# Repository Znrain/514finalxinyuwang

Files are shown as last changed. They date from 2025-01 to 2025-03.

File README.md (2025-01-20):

# 📌 514 Final Project

## 1️⃣ Project Overview
This project is designed to **measure pressure and temperature** using an **MS5837-30BA sensor** and display the results using a **stepper-motor-driven gauge needle**. The system is powered by an **ESP32-S3 microcontroller**, which processes the data and transmits it wirelessly if needed.

### **Physical Features:**
- **Sensor Device**: MS5837-30BA pressure and temperature sensor.
- **Processing Unit**: ESP32-S3 for data collection and control.
- **Display Device**: A stepper-motor-driven gauge needle for analog-style visualization.
- **Power Source**: LiPo battery for wireless operation.

**System Architecture Sketch:**  
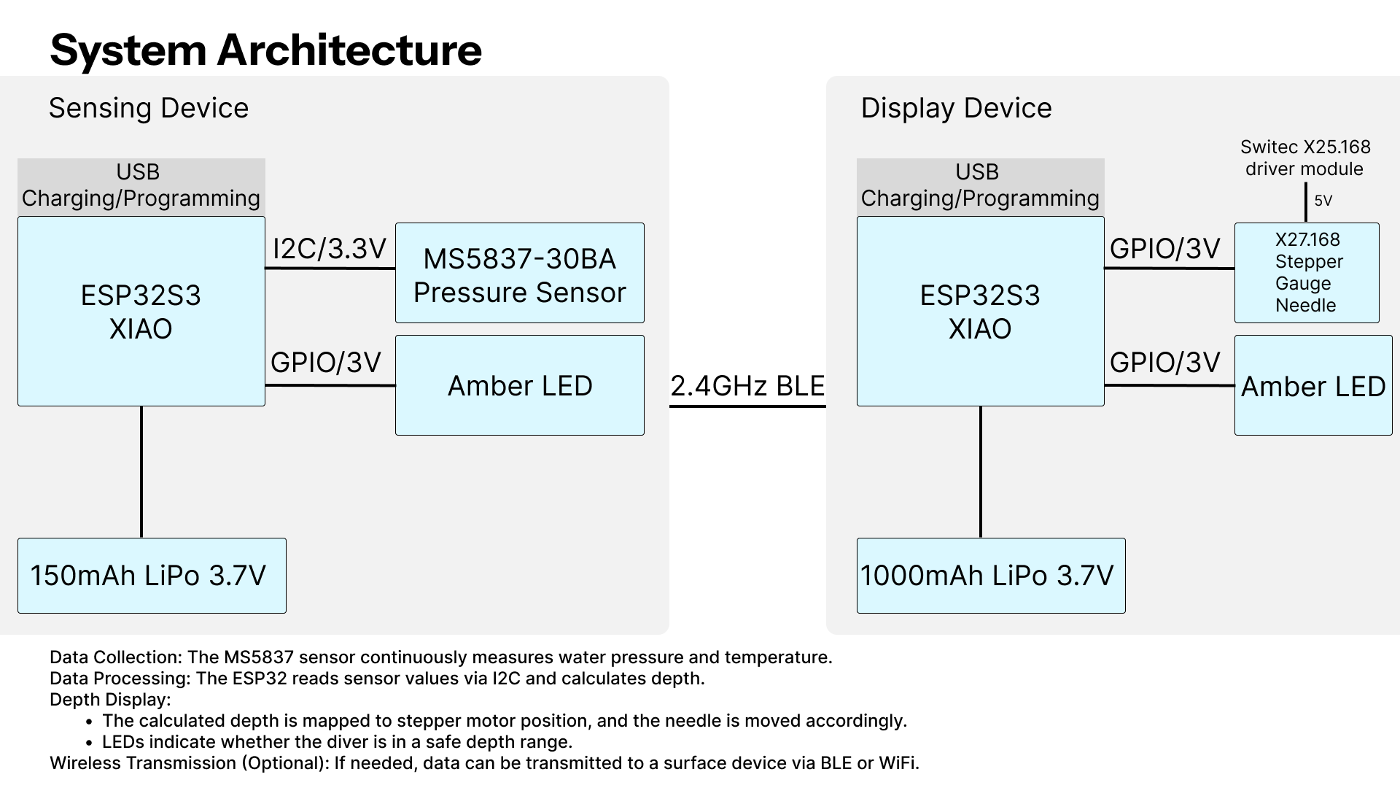
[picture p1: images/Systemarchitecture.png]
System Architecture


---

## 2️⃣ Sensor Device: MS5837-30BA
The **MS5837-30BA** is a **pressure and temperature sensor** that communicates with the ESP32-S3 via the **I2C protocol**. It is used to measure environmental **pressure** and **temperature** in real-time.

### **How it Works:**
- The **sensor measures pressure** in millibars (mbar) and **temperature** in degrees Celsius (°C).
- It transmits data to the **ESP32-S3 via I2C**.
- The ESP32 processes the data and prepares it for display.

### **Sensor Diagram:**
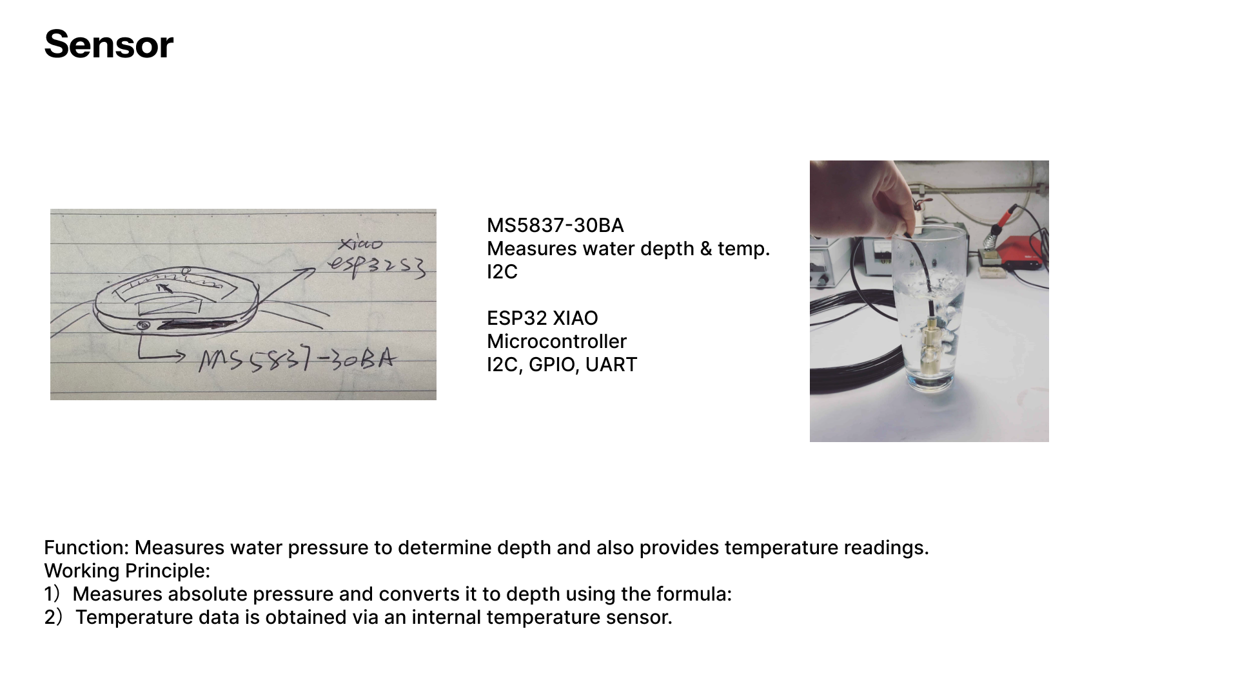
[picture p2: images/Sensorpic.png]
Sensor Device


### **Sensor Part Number:**
- **Pressure & Temperature Sensor**: MS5837-30BA  

---

## 3️⃣ Display Device: Stepper-Motor-Driven Gauge Needle
The **stepper motor with a gauge needle** provides an **analog-style display** of pressure readings. The needle moves proportionally to the measured pressure.

### **How it Works:**
- The **ESP32-S3** sends control signals to the **motor driver**.
- The **stepper motor rotates** to move the gauge needle.
- The **needle position** corresponds to the measured pressure.
- The **display updates in real-time**.

### **Display Diagram:**
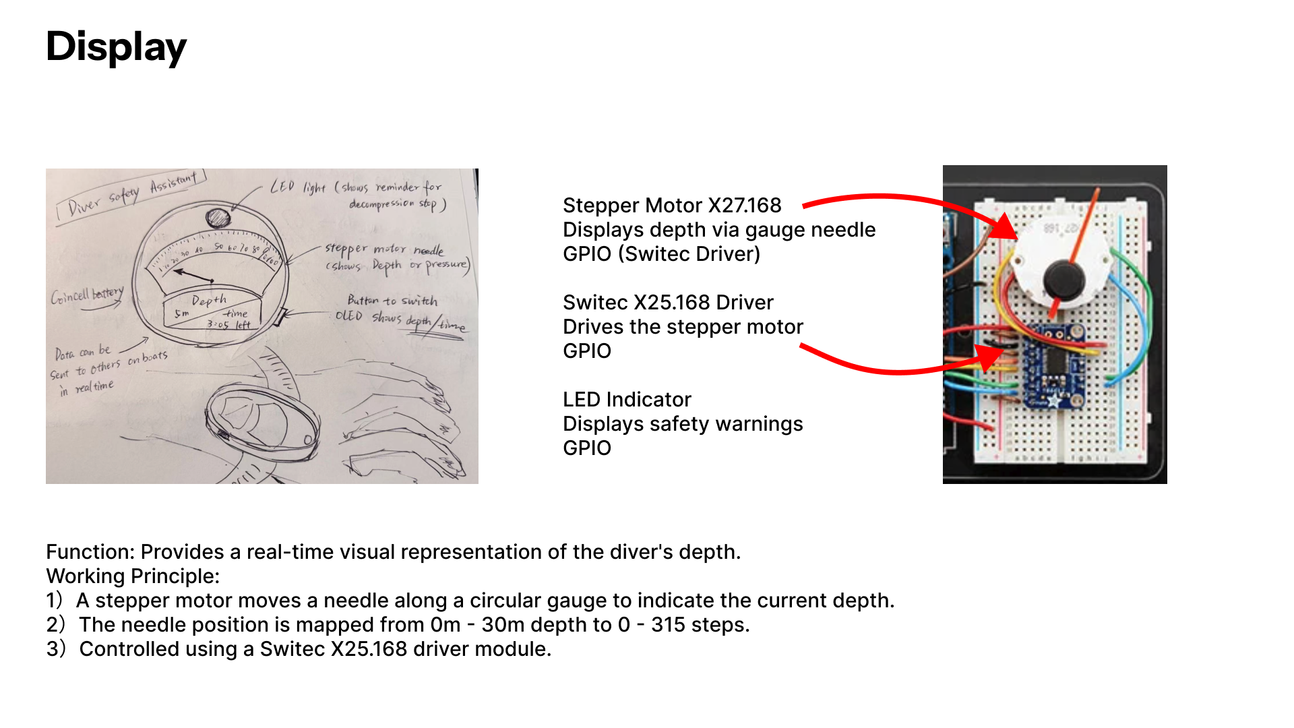
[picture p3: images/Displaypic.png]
Display Device


### **Display Components & Part Numbers:**
- **Stepper Motor**: X25-589  
- **Motor Driver**: SP_X27_e_C  

---

## 4️⃣ System Communication & Detailed Diagram
The **ESP32-S3** acts as the central unit, reading sensor data, processing it, and sending commands to the display.

### **Communication Flow:**
1. **MS5837-30BA sensor** measures pressure and temperature.
2. The sensor **sends data via I2C** to the ESP32-S3.
3. The **ESP32 processes the data** and converts it into a stepper motor signal.
4. The **motor driver (SP_X27_e_C) moves the gauge needle** to display pressure.
5. Optional: **Wireless transmission** can be added using **ESP32's 2.4GHz antenna**.

### **System Diagram:**
**Device Communication Chart**:  
System Architecture

---

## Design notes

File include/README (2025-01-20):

# Diver Safety Assistant

## 🌊 Overview
This is a **diving assistant device** that helps divers track **depth and temperature** in real-time. The system consists of:
- **A sensor device** attached to the diver that collects water depth and temperature data.
- **A display device** that shows real-time depth and alerts the diver using an LED.

## 🎨 Sketch
Project Sketch

---
## 🔗 System Architecture

### **How Devices Communicate**
System Communication Diagram

### **Function Details**
Function Flowchart

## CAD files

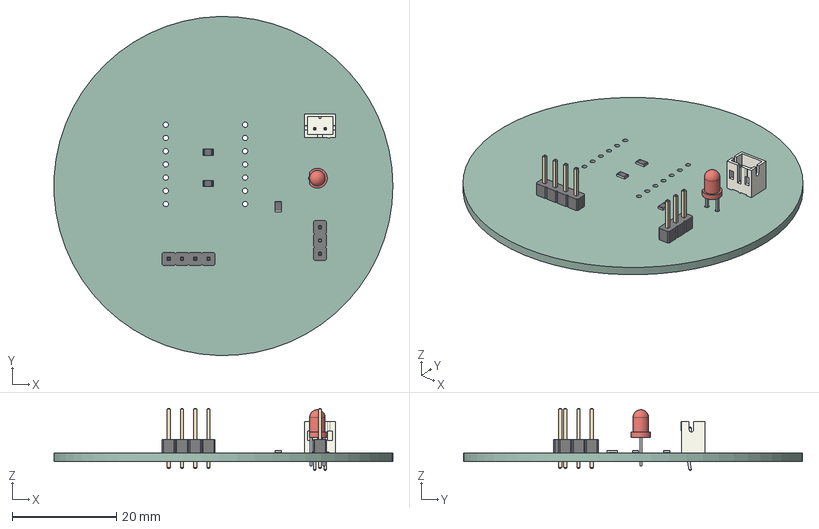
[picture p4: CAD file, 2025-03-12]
PCBSTEPexport/514finalsensor.step
65.1 x 65.1 x 11.9 mm
LED_D3.0mm
PinHeader_1x04_P254mm_Vertical
JST_B2B_PH_K
PinHeader_1x03_P254mm_Vertical
R_0805_2012Metric x 3
514finalsensor_PCB

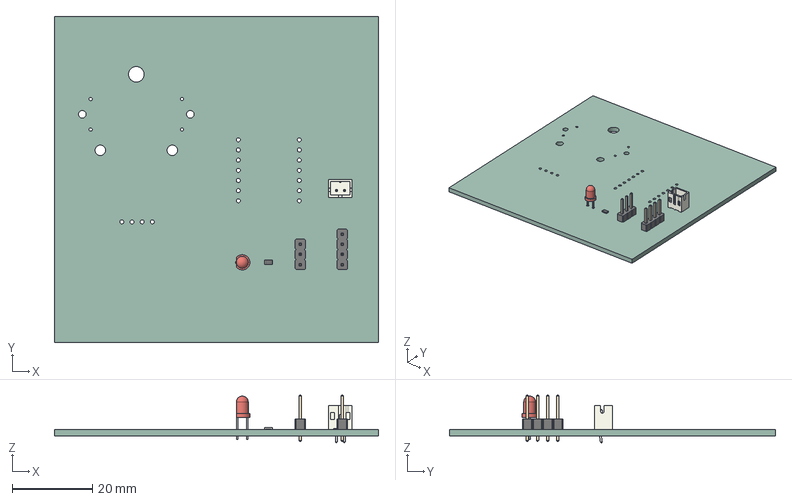
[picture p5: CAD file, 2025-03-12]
PCBSTEPexport/514finalpcbdesign.step
81.0 x 81.5 x 11.9 mm
PinHeader_1x04_P254mm_Vertical
R_0805_2012Metric
PinHeader_1x03_P254mm_Vertical
LED_D3.0mm
JST_B2B_PH_K
514finalpcbdesign_PCB

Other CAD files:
PCBSTEPexport/514finalshell v5.f3d

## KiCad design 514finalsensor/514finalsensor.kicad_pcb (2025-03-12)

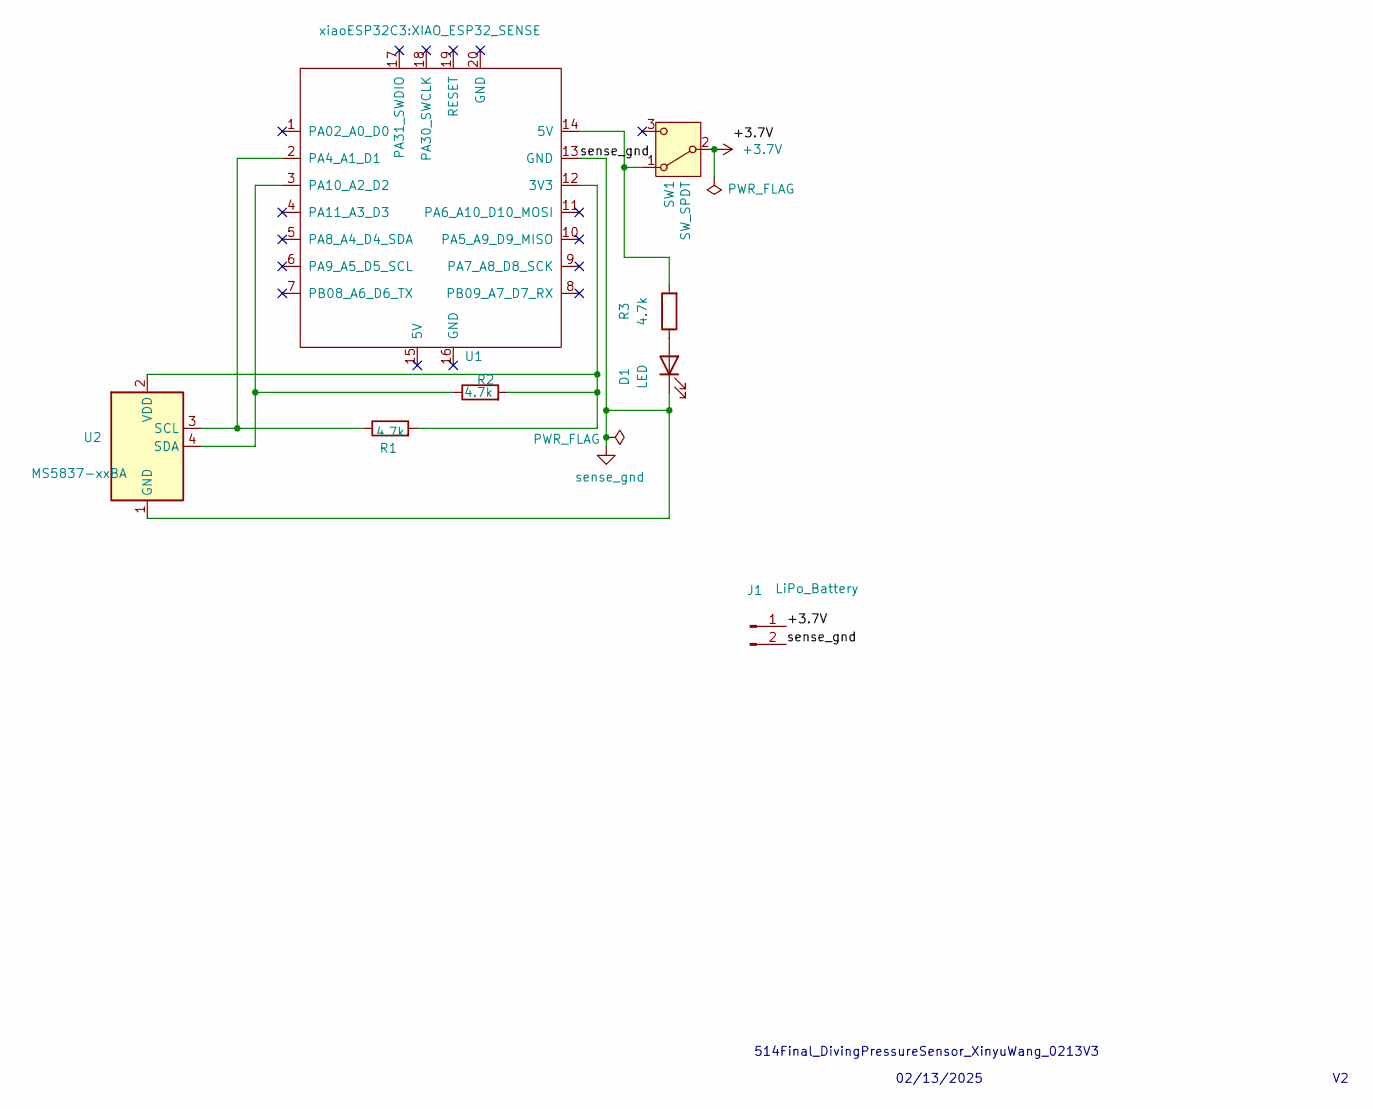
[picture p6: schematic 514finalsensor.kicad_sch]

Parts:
D1: LED; LED_D3.0mm
J1: LiPo_Battery; JST_PH_B2B-PH-K_1x02_P2.00mm_Vertical
R1, R2, R3: 4.7k; R_0805_2012Metric_Pad1.20x1.40mm_HandSolder
SW1: SW_SPDT; PinHeader_1x03_P2.54mm_Vertical
U1: SeeeduinoXIAO; XIAO_ESP32_SENSE
U2: MS5837-xxBA; PinHeader_1x04_P2.54mm_Vertical

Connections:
+3.7V: J1.1, SW1.2 (B)
unnamed: D1.2 (A), R3.1
unnamed: R3.2, SW1.1 (A), U1.14 (5V)
unnamed: R1.2, R2.2, U1.12 (3V3), U2.2 (VDD)
unnamed: R1.1, U1.2 (PA4_A1_D1), U2.3 (SCL)
unnamed: R2.1, U1.3 (PA10_A2_D2), U2.4 (SDA)
sense_gnd: D1.1 (K), J1.2, U1.13 (GND), U2.1 (GND)

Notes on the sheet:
514Final_DivingPressureSensor_XinyuWang_0213V3
02/13/2025

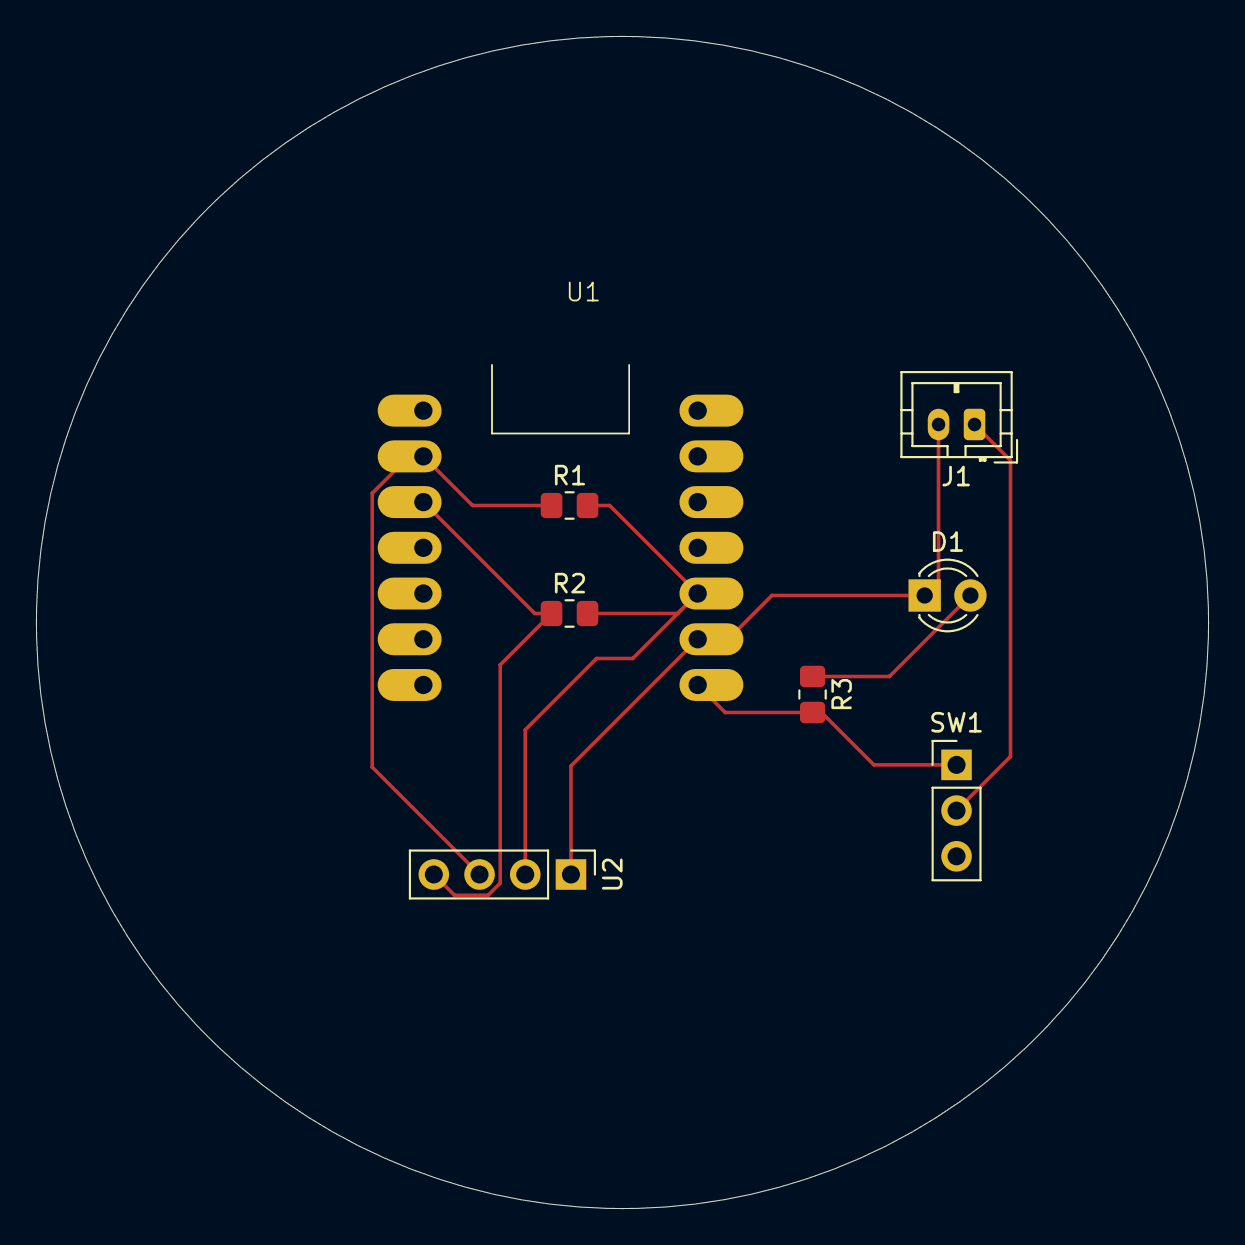
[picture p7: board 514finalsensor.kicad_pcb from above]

Board: 2 copper layers, 65.1 x 65.1 mm, 8 parts (0 on the bottom side), 7 nets.

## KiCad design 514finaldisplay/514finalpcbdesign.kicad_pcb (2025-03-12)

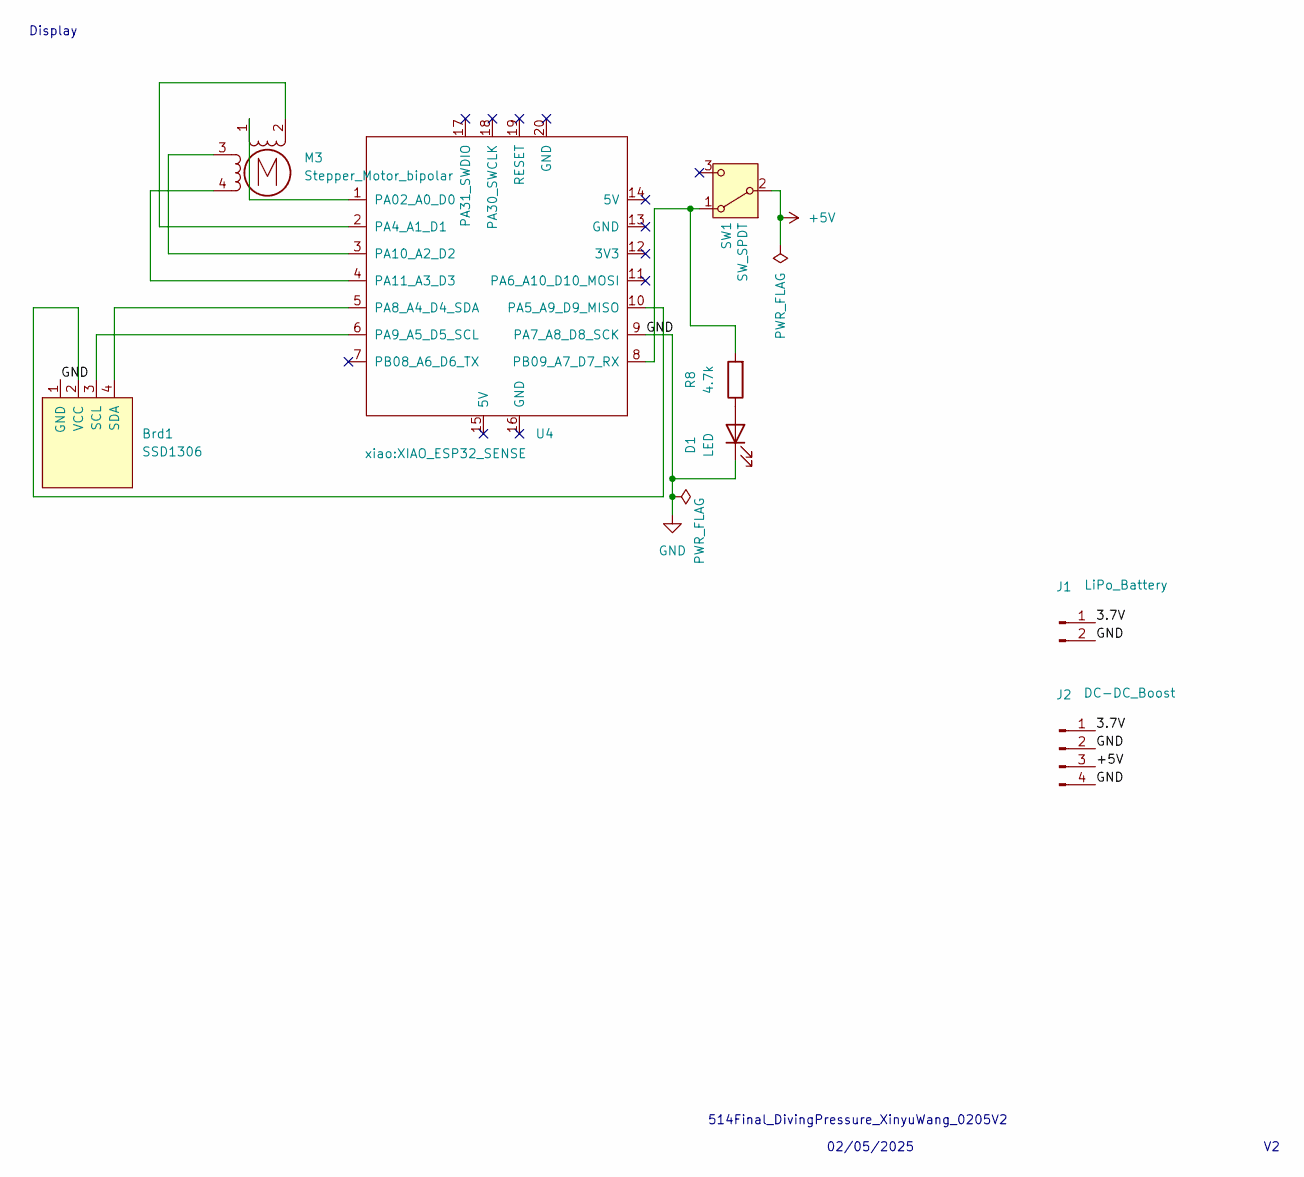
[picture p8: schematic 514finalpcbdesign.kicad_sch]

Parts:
Brd1: SSD1306; 128x64OLED
D1: LED; LED_D3.0mm
J1: LiPo_Battery; JST_PH_B2B-PH-K_1x02_P2.00mm_Vertical
J2: DC-DC_Boost; PinHeader_1x04_P2.54mm_Vertical
M3: Stepper_Motor_bipolar; x27_stepper_two_holes
R8: 4.7k; R_0805_2012Metric_Pad1.20x1.40mm_HandSolder
SW1: SW_SPDT; PinHeader_1x03_P2.54mm_Vertical
U4: SeeeduinoXIAO; XIAO_ESP32_SENSE

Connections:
+5V: J2.3, SW1.2 (B)
/3.7V: J1.1, J2.1
GND: Brd1.1 (GND), D1.1 (K), J1.2, J2.2, J2.4, U4.9 (PA7_A8_D8_SCK)
unnamed: Brd1.3 (SCL), U4.6 (PA9_A5_D5_SCL)
unnamed: Brd1.4 (SDA), U4.5 (PA8_A4_D4_SDA)
unnamed: Brd1.2 (VCC), U4.10 (PA5_A9_D9_MISO)
unnamed: D1.2 (A), R8.1
unnamed: M3.2 (-), U4.2 (PA4_A1_D1)
unnamed: R8.2, SW1.1 (A), U4.8 (PB09_A7_D7_RX)
unnamed: M3.1, U4.1 (PA02_A0_D0)
unnamed: M3.3, U4.3 (PA10_A2_D2)
unnamed: M3.4, U4.4 (PA11_A3_D3)

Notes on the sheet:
514Final_DivingPressure_XinyuWang_0205V2
Display
02/05/2025

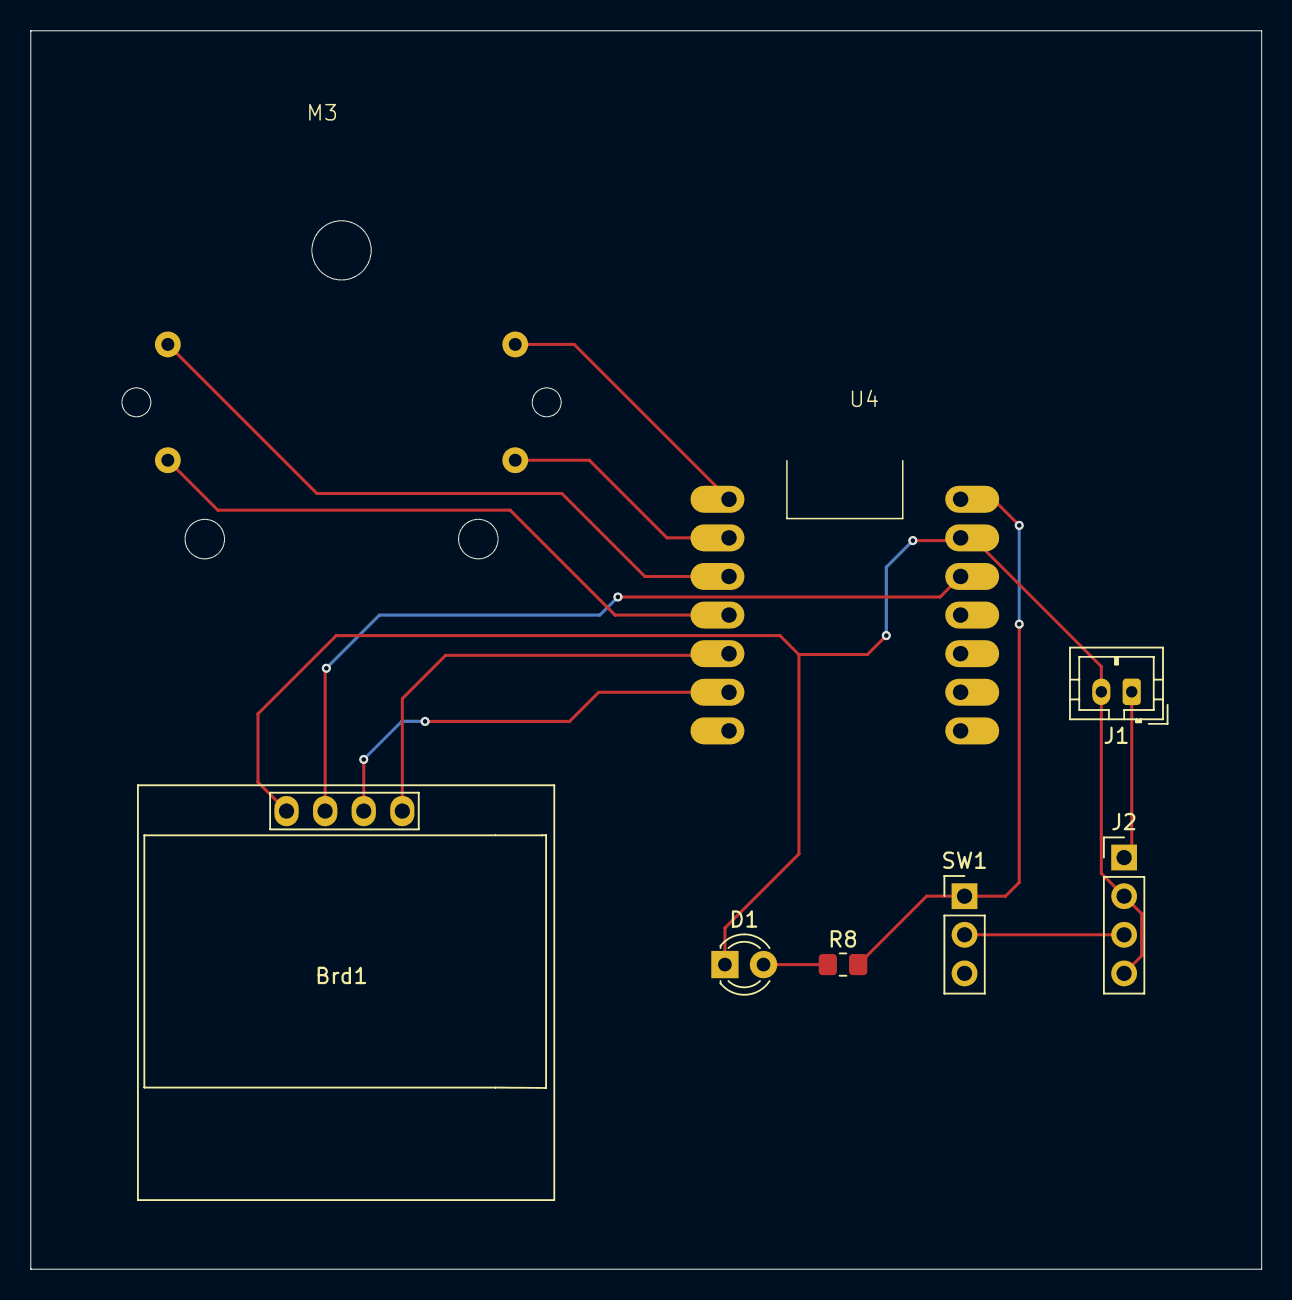
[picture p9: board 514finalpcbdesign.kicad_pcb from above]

Board: 2 copper layers, 81.0 x 81.5 mm, 8 parts (0 on the bottom side), 12 nets.

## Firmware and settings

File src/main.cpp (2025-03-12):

#include <Arduino.h>
#include <Wire.h>
#include <BLEDevice.h>
#include <BLEServer.h>
#include <BLEUtils.h>
#include <BLE2902.h>
#include <MS5837.h>  // 需安装 BlueRobotics_MS5837_Library

// 与 Client 一致的 UUID
#define SERVICE_UUID        "2f22b6ad-51df-4f4c-9a3c-9f902d12c464"
#define CHARACTERISTIC_UUID "f7089b06-e82a-44bc-935a-2f31628f11c9"

MS5837 sensor;
BLEServer* pServer = nullptr;
BLECharacteristic* pCharacteristic = nullptr;
bool deviceConnected = false;
bool oldDeviceConnected = false;

// 每隔 1 秒发送一次数据
unsigned long previousMillis = 0;
const long interval = 1000; // 1 秒

// ========== 1. 定义滑动平均滤波器 ==========
#define FILTER_SIZE 5  // 缓冲区大小，可根据需要调整
float pressureBuffer[FILTER_SIZE];
int bufferIndex = 0;
bool bufferFilled = false;

// 初始化滤波缓冲
void initFilter() {
  for (int i = 0; i < FILTER_SIZE; i++) {
    pressureBuffer[i] = 0.0f;
  }
  bufferIndex = 0;
  bufferFilled = false;
}

// 向滤波缓冲区添加新数据
void addPressure(float p) {
  pressureBuffer[bufferIndex] = p;
  bufferIndex = (bufferIndex + 1) % FILTER_SIZE;
  if (bufferIndex == 0) {
    bufferFilled = true;  // 环形缓冲转一圈后标记为填满
  }
}

// 获取当前缓冲区的平均值（若未填满，则只平均已存的数据）
float getAveragePressure() {
  int count = bufferFilled ? FILTER_SIZE : bufferIndex;
  if (count == 0) return 0.0f;

  float sum = 0.0f;
  for (int i = 0; i < count; i++) {
    sum += pressureBuffer[i];
  }
  return sum / count;
}

class MyServerCallbacks : public BLEServerCallbacks {
  void onConnect(BLEServer* pServer) {
    deviceConnected = true;
    Serial.println("Client connected.");
  }
  void onDisconnect(BLEServer* pServer) {
    deviceConnected = false;
    Serial.println("Client disconnected.");
  }
};

void setup() {
  Serial.begin(115200);
  Serial.println("Starting MS5837 BLE Server with DSP (Moving Average)...");

  // 1. 初始化 I2C
  Wire.begin();
  // 2. 初始化 MS5837
  if (!sensor.init()) {
    Serial.println("MS5837 sensor not found. Check wiring!");
    while (1) { delay(10); }
  }
  sensor.setModel(MS5837::MS5837_30BA); // 如果是 02BA, 改成 MS5837_02BA
  sensor.setFluidDensity(997);         // 淡水约997, 海水约1029~1030

  // 初始化滤波器
  initFilter();

  // 3. 初始化 BLE
  BLEDevice::init("WaterPressure_Server");
  pServer = BLEDevice::createServer();
  pServer->setCallbacks(new MyServerCallbacks());

  // 4. 创建 Service & Characteristic
  BLEService* pService = pServer->createService(SERVICE_UUID);
  pCharacteristic = pService->createCharacteristic(
    CHARACTERISTIC_UUID,
    BLECharacteristic::PROPERTY_READ |
    BLECharacteristic::PROPERTY_NOTIFY
  );
  pCharacteristic->addDescriptor(new BLE2902()); // 允许 notify
  pService->start();

  // 5. 广播
  BLEAdvertising* pAdvertising = BLEDevice::getAdvertising();
  pAdvertising->addServiceUUID(SERVICE_UUID);
  pAdvertising->setScanResponse(true);
  pAdvertising->start();

  Serial.println("BLE Server started, now advertising...");
}

void loop() {
  // 若客户端已连接，每秒读取 MS5837 并发送通知
  if (deviceConnected) {
    unsigned long currentMillis = millis();
    if (currentMillis - previousMillis >= interval) {
      previousMillis = currentMillis;

      // 1. 读取传感器
      sensor.read();
      float rawPressure_mbar = sensor.pressure();   // 原始压力 (mbar)
      float temperature_C = sensor.temperature();    // 温度 (°C)

      // 2. 滤波：将最新压力值加入缓冲，取平均值
      addPressure(rawPressure_mbar);
      float smoothedPressure = getAveragePressure();

      // 3. 拼接字符串 (发送平滑后的压力)
      char buffer[64];
      snprintf(buffer, sizeof(buffer),
               "P=%.2f mbar, T=%.2f C", smoothedPressure, temperature_C);

      // 4. 设置特征值并 notify
      pCharacteristic->setValue(buffer);
      pCharacteristic->notify();

      Serial.print("Notify (DSP): ");
      Serial.println(buffer);
    }
  }

  // 处理断开后重新广播
  if (!deviceConnected && oldDeviceConnected) {
    delay(500);
    pServer->startAdvertising();
    Serial.println("Re-advertising BLE...");
    oldDeviceConnected = deviceConnected;
  }
  if (deviceConnected && !oldDeviceConnected) {
    oldDeviceConnected = deviceConnected;
  }
}

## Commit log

2025-01-20 Add sensor and display device descriptions
2025-01-20 Added datasheets for ESP32-S3, MS5837-30BA, stepper motor, and driver
2025-01-20 Added images folder with architecture and sensor/display images
2025-01-28 Initial commit - Add KiCAD project
    [514finalpcbdesign.kicad_sch]
2025-03-12 Add PCB, display and sensor files for final project
    [514finalpcbdesign-B_Cu.gbr, 514finalpcbdesign-B_Mask.gbr, 514finalpcbdesign-B_Paste.gbr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]
